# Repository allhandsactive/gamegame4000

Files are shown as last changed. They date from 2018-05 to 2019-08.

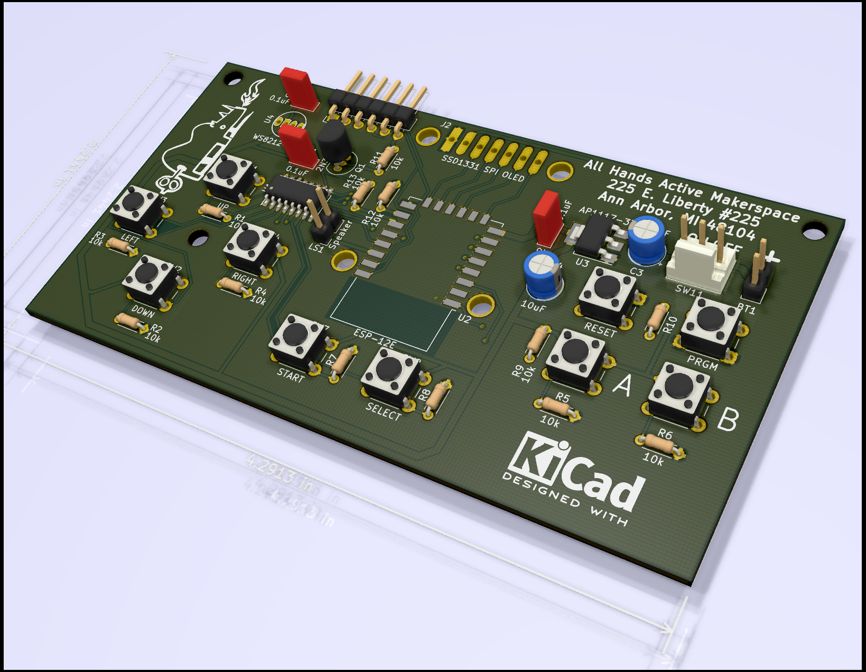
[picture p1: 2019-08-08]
pcb/Gamegame.png

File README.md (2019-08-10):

# gameGame 4000
This is the *gameGame 4000*: an ESP8266-based, wifi-enabled "badge" learn-to-solder project designed for anyone who is interested in soldering on a somewhat intermediate level, or how to program these ubiquitous microcontrollers. Along with the ESP8266, it is equipped with an SSD1331 RGB OLED display, video game controller-alike buttons, and a small speaker for bleeps and bloops.  This kit is designed by *All Hands Active* (http://www.allhandsactive.org), a 501(c)(3) not-for-profit hackerspace (http://hackerspaces.org) located in Downtown Ann Arbor, MI, USA.  The included Arkanoid demo code here is based, almost verbatim, on code from the *ssd1331* library by Alexey Dynda (@lexus2k).  We added some tweaks to accommodate our unique button handling library, and adjusted pins to match our OLED screen setup.

As any good hackerspace should, we encourage people to fully tinker with the code and designs, and to find novel uses for this project.  We'd love to hear of your projects using our badge -- please get in contact with us if you'd like to share your project!

Since it is based on the same processor, much of this documentation is copied over from our last kit, the *mktwo* badge (https://github.com/allhandsactive/mktwo-badge/blob/master/README.md)

# Build instructions on Imgur
Heads up! There are a few errors in the assembly pictures at the imgur link here.  Please follow the instructions in the captions first and foremost: https://imgur.com/gallery/5YhMqiV

### **Kit parts list**

Make sure you have the following in your kit:

1x gameGame 4000 PCB

1x ESP8266 12E or 12F microprocessor

1x SSD1331 OLED display

1x 3-AA battery holder

1x Female battery connector lead with pigtail

1x Male battery connector header

1x Toggle switch

1x Header 7-socket

1x Right-angle header 6-pin

1x Speaker 8-ohm 20mm

1x Linear regulator 1.2A 3.3v STMicroelectronics P/N LDL1117S33R

1x Shift register 8-bit Nexperia USA Inc. P/N 74HC597D,653

2x Electrolytic capacitor 10uF 50V

2x Ceramic capacitor 0.1uF 50V

4x Nylon standoff M2 x 12mm

4x Nylon nut M2

4x Nylon screw M2 x 5mm

10x Push button

12x Resistor 10k Ohm 1/8W 5%

### **Requirements**
#### **Hardware**
The safest and more reliable way to load firmware onto your *gameGame 4000* is with a USB-serial programming cable.  You will need to use an FTDI cable, like the FTDI cable here (https://www.sparkfun.com/products/9717) , *OR* you can use a cheaper cable with the Prolific *PL2303HX* chipset (look on eBay! We were able to easily find them from US sellers for under $5).  A serial voltage level of 3.3v for programming is recommended, but we've safely done it with 5v, too.  **NOTE:** Windows/Apple users, you will likely have to download a driver to use the *PL2303HX*.  Sorry, we can't provide support on how to do that.

Such cables hook up to the FTDI pin block near the bottom of the *gameGame 4000*.  Take care when hooking up the cable, because the FTDI pins on the badge are not keyed.  When you plug it into the badge, make sure the black wire on the FTDI cable faces toward the left side of the badge (assuming you are viewing the front of the badge).  In case your cable doesn't have a single plug, but a bunch of individual wires (like the Prolific ones), the pinout should be as follows, assuming the board is facing up toward you, left-to-right (*NC = No Connection*):

**BLACK NC NC GREEN WHITE NC**

The red wire from the programming cable should not be connected, which also means you will need to power the badge with the battery when programming it.

#### **Software**
We recommend a current version of the Arduino IDE (https://www.arduino.cc/en/Main/Software), either binary or git clone.

Under Arduino's preferences, *Additional Boards Manager URLs*, you will need to add:

`http://arduino.esp8266.com/stable/package_esp8266com_index.json`

Under *Tools|Board:|Boards Manager...* search for and install `esp8266`.
**NOTE: you will need to add the URL above in preferences first.**
You will also need some libraries to run the OLED screen.  Under *Sketch|Include Library|Manage Libraries...* search for `SSD1331`.  Any of those should work to varying degrees.  Try them out and experiment! If you want to try the included `arkanoid8-pcon` demo, grab the `ssd1306` library, which comes with some cool demo stuff for our `SSD1331` OLED screen.  Keep in mind that you will have to update the pin settings on the other demos since they are connected differently for this board.

Now restart the Arduino IDE.

### **Badge Programming**
#### **Wired Programming**
##### **SETUP**

Under the Arduino IDE settings (most of these seem to be defaults):

Board: "NodeMCU 1.0 (ESP-12E Module)"

CPU Frequency: "80 MHz"

Debug Port: "Disabled"

Debug Level: "None"

lwIP Variant: "v2 Lower Memory"

Flash Size: "4M (3M SPIFFS)"

Upload Speed: "460800" (try lowering this if you have issues while programming the board)

Port: (whatever port the programming cable is on.  In Linux, it'll be something like `/dev/ttyUSB0`)

Programmer: "AVRISP mkII"

Erase Flash: "Only Sketch"

##### **PROCEDURE**

Let's take a look at the `ssd1306` library's demo games.  After installing that library, you can load up the `arkanoid8-gamegame` code from this repo.

To upload your code, you need to put the badge into "write" or "programming" mode.  To do this, locate the `PRGM` and `RESET` buttons on the badge.  Hold the `PRGM` button. Press and release the `RESET` button. You may now release `PRGM`. **You will need to repeat this procedure before each firmware upload.**
You may now compile and upload as you would with any Arduino, using the Arduino IDE.

**NOTE: Some FTDI cables might not cause the ESP to reset after successful programming.  If you are observing this behavior, just use the** `RESET` **button on the badge.**

### Other notes
The speaker is linked to pin 5, if you wish to make bleeps and bloops with the `tone` function.

Other pin settings that might be useful:

For the OLED display:

sclk = 14

mosi = 13

cs = 2

rst = 0

dc = 16

For buttons (check out the example code in this repo):

pl/sload = 4

shcp/sck = 0

stcp/clk = 15

shift reg. serial output ("BUTTONS" on schematic) = 10

The board works great with three NiMH AA batteries.

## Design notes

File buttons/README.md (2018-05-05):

# gameGame_Buttons

This is a simple button tester for the upcoming gameGame soldering kit for PenguiCon 2018.

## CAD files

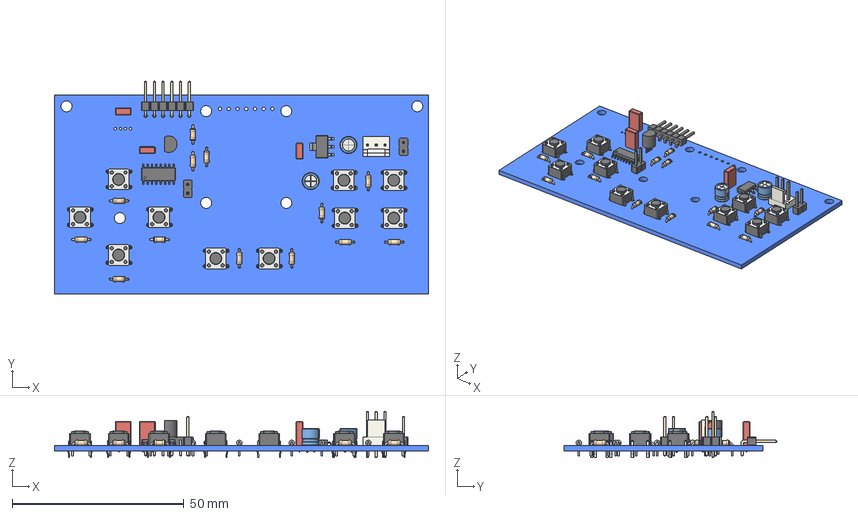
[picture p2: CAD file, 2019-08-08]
pcb/Gamegame.step
108.8 x 61.8 x 13.5 mm
Pcb
C_Rect_L46mm_W20mm_P250mm_MKS02_FKP02_
C_Rect_L46mm_W20mm_P250mm_MKS02_FKP02_001
CP_Radial_D50mm_P200mm_
CP_Radial_D50mm_P200mm_001
C_Rect_L46mm_W20mm_P250mm_MKS02_FKP02_002
PinHeader_1x06_P254mm_Horizontal_
PinHeader_1x02_P254mm_Vertical_
TO-92_Inline_Narrow_
R_Axial_DIN0204_L36mm_D16mm_P508mm_Horizontal_
R_Axial_DIN0204_L36mm_D16mm_P508mm_Horizontal_001
R_Axial_DIN0204_L36mm_D16mm_P508mm_Horizontal_002
R_Axial_DIN0204_L36mm_D16mm_P508mm_Horizontal_003
R_Axial_DIN0204_L36mm_D16mm_P508mm_Horizontal_004
R_Axial_DIN0204_L36mm_D16mm_P508mm_Horizontal_005
R_Axial_DIN0204_L36mm_D16mm_P508mm_Horizontal_006
R_Axial_DIN0204_L36mm_D16mm_P508mm_Horizontal_007
R_Axial_DIN0204_L36mm_D16mm_P508mm_Horizontal_008
R_Axial_DIN0204_L36mm_D16mm_P508mm_Horizontal_009
R_Axial_DIN0204_L36mm_D16mm_P508mm_Horizontal_010
R_Axial_DIN0204_L36mm_D16mm_P508mm_Horizontal_011
R_Axial_DIN0204_L36mm_D16mm_P508mm_Horizontal_012
SW_PUSH_6mm_
SW_PUSH_6mm_001
SW_PUSH_6mm_002
SW_PUSH_6mm_003
SW_PUSH_6mm_004
SW_PUSH_6mm_005
SW_PUSH_6mm_006
SW_PUSH_6mm_007
SW_PUSH_6mm_008
SW_PUSH_6mm_009
Fan_Pin_Header_Straight_1x03_
SOIC_16_39x99mm_P127mm_
SOT_223_
PinHeader_1x02_P254mm_Vertical_001

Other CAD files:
pcb/Gamegame.FCStd

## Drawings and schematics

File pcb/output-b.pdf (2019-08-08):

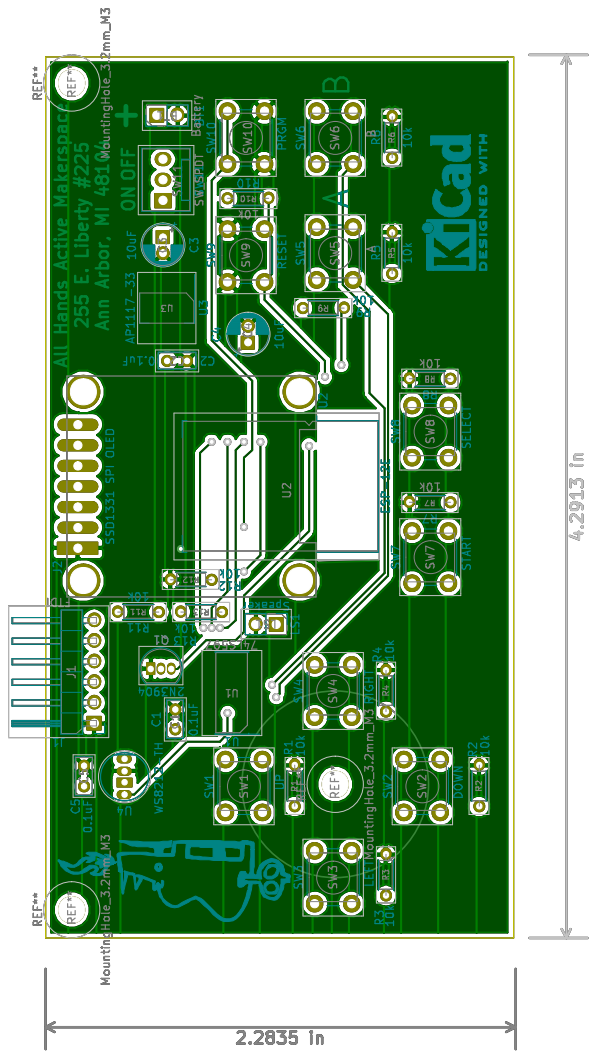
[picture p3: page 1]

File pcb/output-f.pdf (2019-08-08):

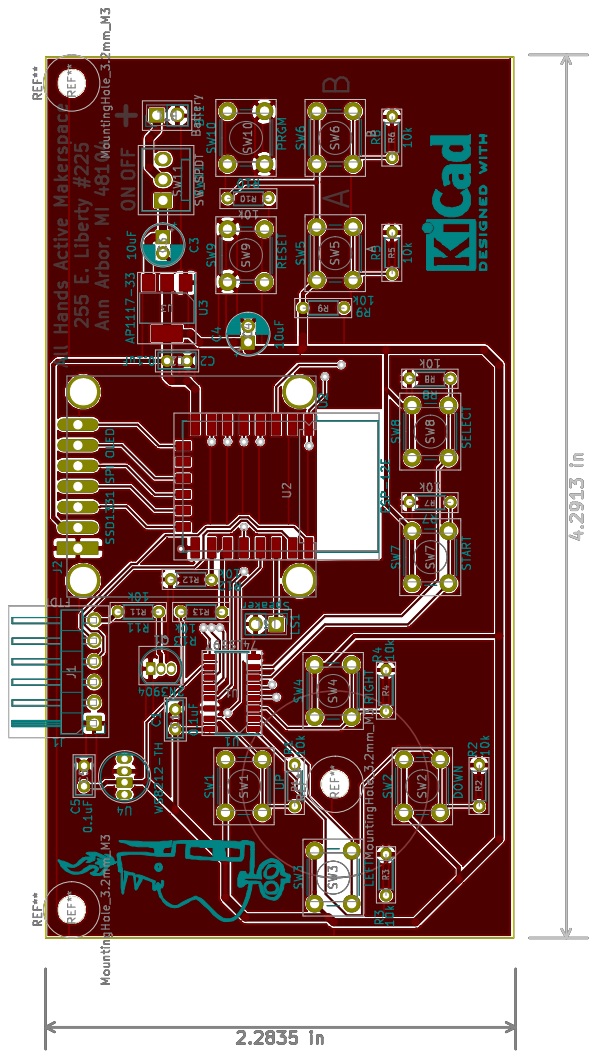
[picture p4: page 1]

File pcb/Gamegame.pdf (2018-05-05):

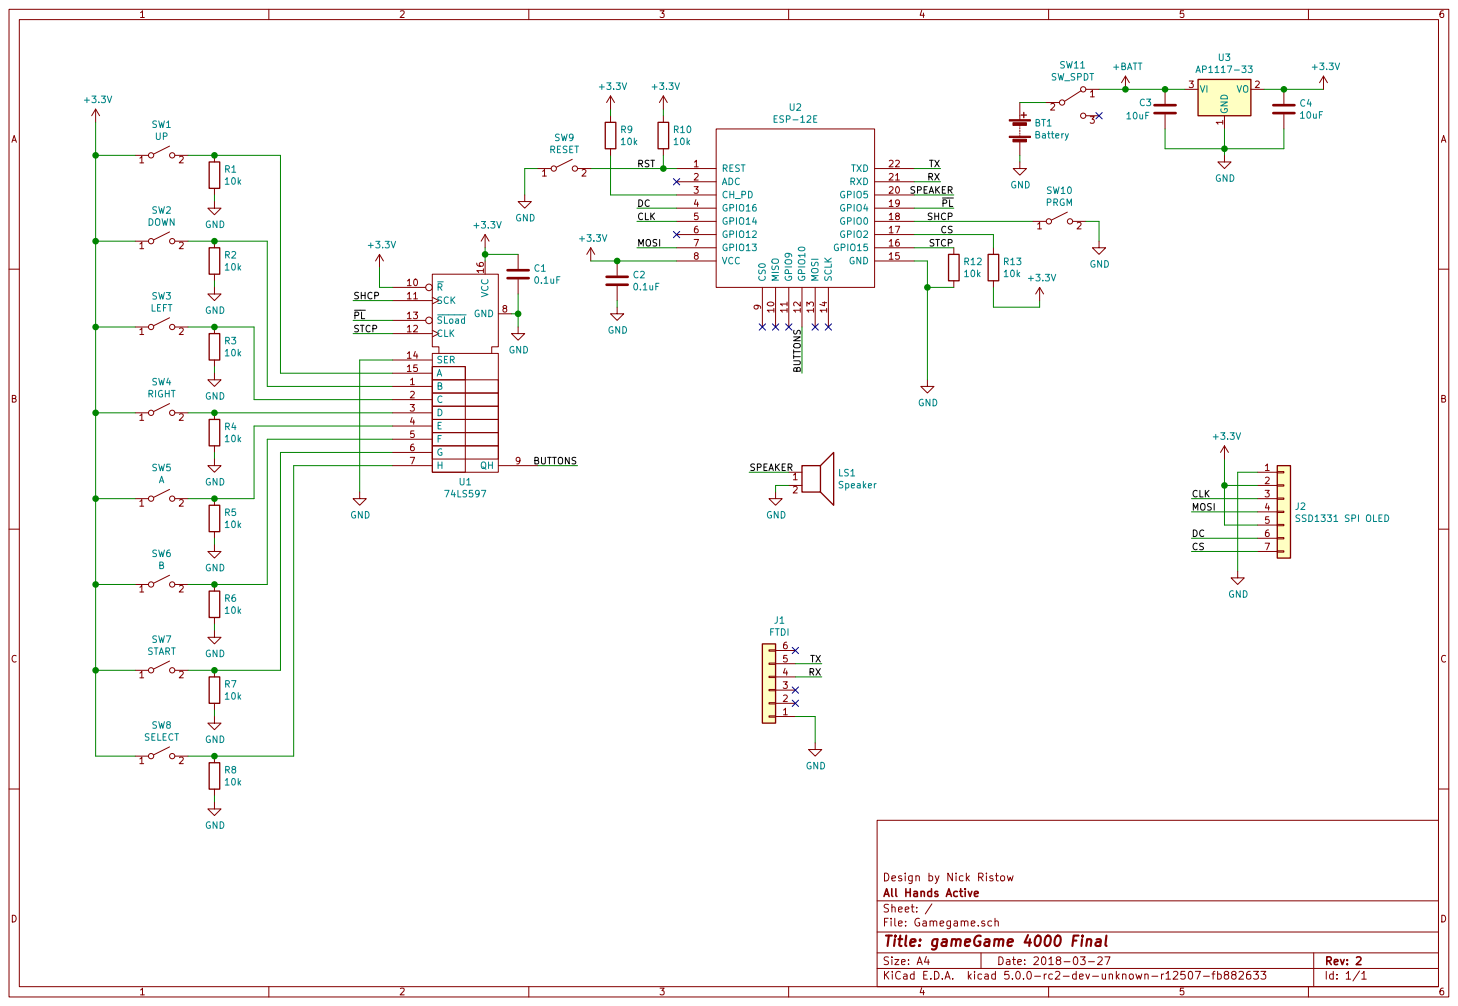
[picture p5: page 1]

File: Gamegame.sch Sheet: / All Hands Active Design by Nick Ristow

Id: 1/1 Title: gameGame 4000 Final

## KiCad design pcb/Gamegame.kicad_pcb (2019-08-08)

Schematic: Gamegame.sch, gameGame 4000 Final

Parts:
BT1: Battery; PinHeader_1x02_P2.54mm_Vertical
C1, C2: 0.1uF; C_Rect_L4.6mm_W2.0mm_P2.50mm_MKS02_FKP02
C3, C4: 10uF; C_Rect_L4.6mm_W2.0mm_P2.50mm_MKS02_FKP02
J1: FTDI; PinHeader_1x06_P2.54mm_Horizontal
J2: SSD1331 SPI OLED; SD1131
LS1: Speaker; PinHeader_1x02_P2.54mm_Vertical
R1, R2, R3, R4, R5, R6, R7, R8, R9, R10, R12, R13: 10k; R_Axial_DIN0204_L3.6mm_D1.6mm_P5.08mm_Horizontal
SW1: UP; SW_PUSH_6mm
SW2: DOWN; SW_PUSH_6mm
SW3: LEFT; SW_PUSH_6mm
SW4: RIGHT; SW_PUSH_6mm
SW5: A; SW_PUSH_6mm
SW6: B; SW_PUSH_6mm
SW7: START; SW_PUSH_6mm
SW8: SELECT; SW_PUSH_6mm
SW9: RESET; SW_PUSH_6mm
SW10: PRGM; SW_PUSH_6mm
SW11: SW_SPDT; FanPinHeader_1x03_P2.54mm_Vertical
U1: 74LS597; SOIC-16_3.9x9.9mm_P1.27mm
U2: ESP-12E
U3: AP1117-33; SOT-223-3_TabPin2

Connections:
+3V3: C1.1, C2.1, C4.1, J2.2, J2.5, R9.1, R10.1, R13.2, SW1.1, SW2.1, SW3.1, SW4.1, SW5.1, SW6.1, SW7.1, SW8.1, U1.10, U1.16, U2.8 (VCC), U3.2 (VO)
+BATT: C3.1, SW11.1, U3.3 (VI)
/BUTTONS: U1.9, U2.12 (GPIO10)
/CLK: J2.3, U2.5 (GPIO14)
/CS: J2.7, R13.1, U2.17 (GPIO2)
/DC: J2.6, U2.4 (GPIO16)
/MOSI: J2.4, U2.7 (GPIO13)
/RST: R10.2, SW9.2, U2.1 (REST)
/RX: J1.4, U2.21 (RXD)
/SHCP: SW10.1, U1.11, U2.18 (GPIO0)
/SPEAKER: LS1.1, U2.20 (GPIO5)
/STCP: R12.1, U1.12, U2.16 (GPIO15)
/TX: J1.5, U2.22 (TXD)
/~PL: U1.13, U2.19 (GPIO4)
GND: BT1.2, C1.2, C2.2, C3.2, C4.2, J1.1, J2.1, LS1.2, R1.2, R2.2, R3.2, R4.2, R5.2, R6.2, R7.2, R8.2, R12.2, SW9.1, SW10.2, U1.8, U1.14, U2.15 (GND), U3.1 (GND)
unnamed: BT1.1, SW11.2
unnamed: R1.1, SW1.2, U1.15
unnamed: R2.1, SW2.2, U1.1
unnamed: R3.1, SW3.2, U1.2
unnamed: R4.1, SW4.2, U1.3
unnamed: R5.1, SW5.2, U1.4
unnamed: R6.1, SW6.2, U1.5
unnamed: R7.1, SW7.2, U1.6
unnamed: R8.1, SW8.2, U1.7
unnamed: R9.2, U2.3 (CH_PD)

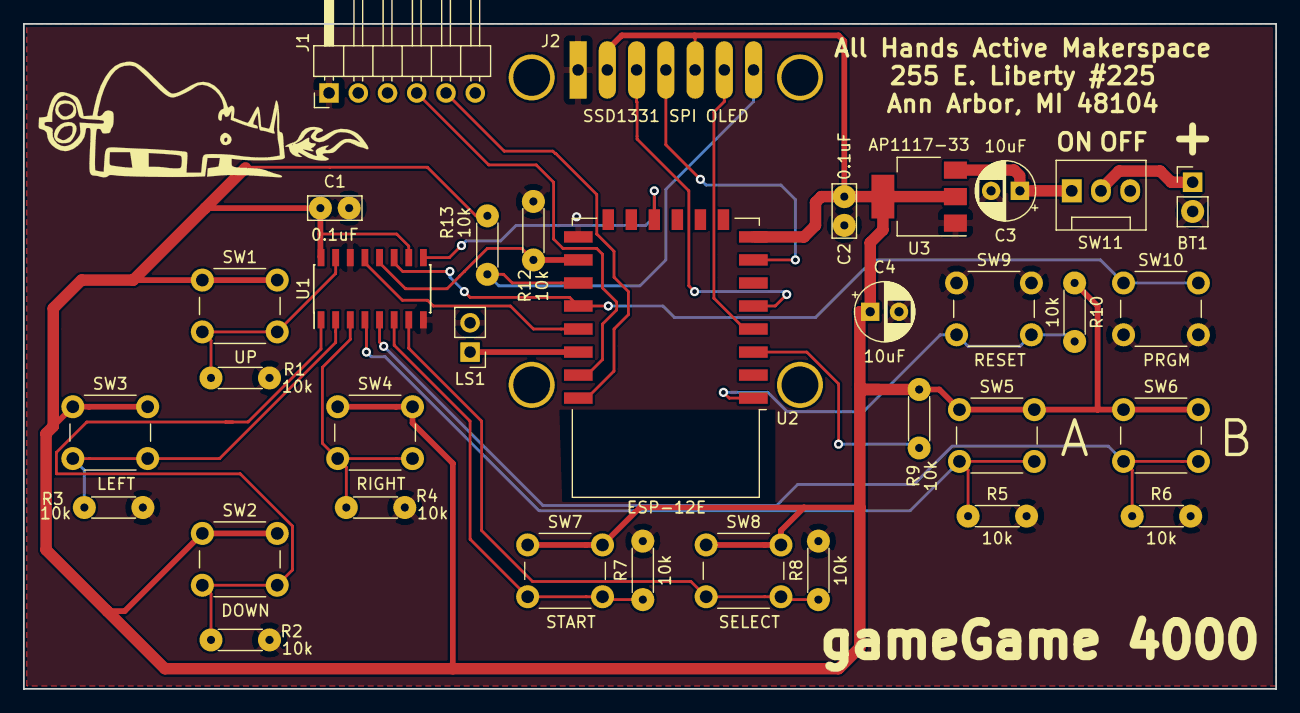
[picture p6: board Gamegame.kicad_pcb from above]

Board: 2 copper layers, 108.8 x 57.8 mm, 34 parts (0 on the bottom side), 25 nets.

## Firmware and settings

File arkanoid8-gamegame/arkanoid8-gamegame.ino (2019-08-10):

/*
    MIT License

    Copyright (c) 2018, Alexey Dynda

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
    THE SOFTWARE IS PROVIDED "AS IS", WITHOUT WARRANTY OF ANY KIND, EXPRESS OR
    IMPLIED, INCLUDING BUT NOT LIMITED TO THE WARRANTIES OF MERCHANTABILITY,
    FITNESS FOR A PARTICULAR PURPOSE AND NONINFRINGEMENT. IN NO EVENT SHALL THE
    AUTHORS OR COPYRIGHT HOLDERS BE LIABLE FOR ANY CLAIM, DAMAGES OR OTHER
    LIABILITY, WHETHER IN AN ACTION OF CONTRACT, TORT OR OTHERWISE, ARISING FROM,
    OUT OF OR IN CONNECTION WITH THE SOFTWARE OR THE USE OR OTHER DEALINGS IN THE
    SOFTWARE.
*/
/**
 *   Nano/Atmega328 PINS: connect LCD to D5 (D/C), D4 (CS), D3 (RES), D11(DIN), D13(CLK)
 *   Attiny SPI PINS:     connect LCD to D4 (D/C), GND (CS), D3 (RES), D1(DIN), D2(CLK)
 *   ESP8266: connect LCD to D1(D/C), D2(CS), RX(RES), D7(DIN), D5(CLK)
 */

#include "ssd1306.h"
#include "nano_engine.h"

#include "arkanoid.h"
#include "levels.h"

#define PIX_BITS  2

#include <buttons.h>

//Set up the buttons for the gameGame 4000.  See the `button` code for more info.
Buttons button(4,0,15,10);

#define SPEAKER 5

NanoEngine8 engine;

static uint8_t g_level = 0;
static uint8_t g_score = 0;
static const NanoRect gameArea = { {16, 0}, {79, 63} };
static const NanoRect blockArea = { {0, 8},
                                    {BLOCKS_PER_ROW*8 - 1, 8 + BLOCK_NUM_ROWS*4 - 1} };

union
{
    struct
    {
        lcdint_t intro_y;
        lcdint_t pauseFrames;
    } intro;
    struct
    {
        lcdint_t intro_y;
        lcdint_t pauseFrames;
    } info;
    struct
    {
        NanoRect  platform;  // platform position on the screen
        NanoPoint ball;      // ball position on the screen
        NanoPoint ballScaled;// ball position in ^PIX_BITS coordinates
        NanoPoint ballSpeed; // ball speed in *2 coordinates
        uint8_t   blocks[BLOCK_NUM_ROWS][MAX_BLOCKS_PER_ROW];
        uint8_t   blocksLeft;
        uint8_t   frames;
    } battleField;
} gameState;

void startBattleField(bool reload);

bool drawIntro(void)
{
    engine.canvas.clear();
    engine.canvas.setColor(RGB_COLOR8(255,0,0));
    engine.canvas.drawBitmap1(0, gameState.intro.intro_y, 96, 24, arkanoid_2);
    return true;
}

void introLoop(void)
{
    if (gameState.intro.intro_y < 16)
    {
        engine.refresh( 0, gameState.intro.intro_y, 95, gameState.intro.intro_y + 24 );
        gameState.intro.intro_y++;
    }
    else
    {
        gameState.intro.pauseFrames++;
        if (gameState.intro.pauseFrames > engine.getFrameRate() * 3 )
        {
            startBattleField( true );
        }
    }
}

void startIntro(void)
{
    engine.refresh();
    g_level = 0;
    g_score = 0;
    gameState.intro.intro_y = -24;
    gameState.intro.pauseFrames = 0;
    engine.drawCallback( drawIntro );
    engine.loopCallback( introLoop );
}

bool drawBattleField(void)
{
    /* If engine requests to redraw main game field */
    if (gameArea.contains(engine.canvas.rect()))
    {
        /* Set non-transparent mode */
        engine.canvas.setMode(CANVAS_MODE_BASIC);
        engine.canvas.setColor(RGB_COLOR8(0,0,64));
        NanoRect tileBlocks = engine.canvas.rect() >> 3;
        tileBlocks.crop(gameArea >> 3);
        for (uint8_t row = tileBlocks.p1.y; row <= tileBlocks.p2.y; row++)
            for (uint8_t col = tileBlocks.p1.x; col <= tileBlocks.p2.x; col++)
                engine.canvas.drawBitmap1(col << 3, row << 3, 8, 8, bgTile);
        engine.canvas.setColor(RGB_COLOR8(255,255,255));
        engine.canvas.drawHLine(gameArea.p1.x,gameArea.p1.y,gameArea.p2.x);

        /* Now draw everything in game coordinates */
        engine.worldCoordinates();
        engine.canvas.setColor(RGB_COLOR8(0,128,255));
        engine.canvas.drawRect(gameState.battleField.platform);
        engine.canvas.setColor(RGB_COLOR8(0,0,0));
        engine.canvas.putPixel(gameState.battleField.platform.p1);
        engine.canvas.putPixel(gameState.battleField.platform.p2.x,
                               gameState.battleField.platform.p1.y);
        for (uint8_t r = 0; r<BLOCK_NUM_ROWS; r++)
        {
            for (uint8_t bl = 0; bl<BLOCKS_PER_ROW; bl++)
            {
                uint8_t block = gameState.battleField.blocks[r][bl];
                if (block)
                {
                     NanoRect rect = {{bl*8, r*4}, {bl*8 + 8, r*4+4}};
                     rect += blockArea.p1;
                     engine.canvas.setColor(blockColors[block]);
                     engine.canvas.fillRect(rect);
                     engine.canvas.setColor(0);
                     engine.canvas.drawRect(rect);
                }
            }
         }
         engine.canvas.setColor(RGB_COLOR8(255,255,255));
         engine.canvas.putPixel(gameState.battleField.ball);
    }
    else
    {
        char str[8] = {0};
        engine.canvas.clear();
        engine.canvas.setColor(RGB_COLOR8(255,255,255));
        engine.canvas.drawVLine(gameArea.p1.x-1,0,64);
        engine.canvas.drawVLine(gameArea.p2.x+1,0,64);
        utoa(g_score, str, 10);
        engine.canvas.setColor(RGB_COLOR8(192,192,192));
        engine.canvas.printFixed(gameArea.p2.x+3, 16, str );
    }
    return true;
}

/* Moves platform right or left according to pressed keys */
void movePlatform(void)
{
    //Here is another change to make the inputs work on the gameGame 4000.
    uint8_t but = button.readButtons();
    

    if ((but & Buttons::LEFT) && (gameState.battleField.platform.p1.x > 0))
    {
        engine.refreshWorld( gameState.battleField.platform );
        gameState.battleField.platform.move(-1, 0);
        engine.refreshWorld( gameState.battleField.platform );
    }
    if ((but & Buttons::RIGHT) && (gameState.battleField.platform.p2.x < gameArea.width() - 1))
    {
        engine.refreshWorld( gameState.battleField.platform );
        gameState.battleField.platform.move(+1, 0);
        engine.refreshWorld( gameState.battleField.platform );
    }
}

bool checkBlockHit(void)
{
    if (!blockArea.collision(gameState.battleField.ball))
    {
        return false;
    }
    NanoPoint p = gameState.battleField.ball - blockArea.p1;
    uint8_t row = p.y >> 2;
    uint8_t column = p.x >> 3;
    if (!gameState.battleField.blocks[row][column])
    {
        return false;
    }
    gameState.battleField.blocks[row][column] = 0;
    gameState.battleField.blocksLeft--;
    g_score++;
    engine.refreshWorld( gameArea.p2.x + 1, 0, 95, 63 );
    if (((p.y & 3) == 2) || (p.y & 3) == 1)
    {
        gameState.battleField.ballSpeed.x = -gameState.battleField.ballSpeed.x;
    }
    else
    {
        gameState.battleField.ballSpeed.y = -gameState.battleField.ballSpeed.y;
    }
    engine.refreshWorld( gameState.battleField.ball );
    return true;
}

bool checkPlatformHit()
{
    if (gameState.battleField.platform.collisionX( gameState.battleField.ball.x ) &&
        !gameState.battleField.platform.above( gameState.battleField.ball ) &&
        !gameState.battleField.platform.below( gameState.battleField.ball ) )
    {
        if (gameState.battleField.ball.x < gameState.battleField.platform.p1.x + 3)
        {
            gameState.battleField.ballSpeed.x = -3;
            gameState.battleField.ballSpeed.y = -gameState.battleField.ballSpeed.y;
        }
        else if (gameState.battleField.ball.x > gameState.battleField.platform.p2.x - 3)
        {
            gameState.battleField.ballSpeed.x = +3;
            gameState.battleField.ballSpeed.y = -gameState.battleField.ballSpeed.y;
        }
        else
        {
            gameState.battleField.ballSpeed.x = gameState.battleField.ballSpeed.x > 0 ? 2: -2;
            gameState.battleField.ballSpeed.y = -gameState.battleField.ballSpeed.y;
        }
        return true;
    }
    return false;
}

bool checkGameAreaHit(void)
{
    bool hit = false;
    if ((gameState.battleField.ball.x < 0) ||
        (gameState.battleField.ball.x >= gameArea.width()))
    {
        hit = true;
        gameState.battleField.ballSpeed.x = -gameState.battleField.ballSpeed.x;
    }
    if ((gameState.battleField.ball.y < 0) ||
        (gameState.battleField.ball.y >= gameArea.height()))
    {
        hit = true;
        gameState.battleField.ballSpeed.y = -gameState.battleField.ballSpeed.y;
        if (gameState.battleField.ball.y >= gameArea.height())
        {
             startBattleField( false );
        }
    }
    return hit;
}

void moveBall(void)
{
    engine.refreshWorld( gameState.battleField.ball );
    bool moveBall;
    do
    {
        gameState.battleField.ballScaled += gameState.battleField.ballSpeed;
        gameState.battleField.ball = gameState.battleField.ballScaled >> PIX_BITS;
        moveBall = false;
        if (checkGameAreaHit())
        {
            moveBall = true;
            tone(SPEAKER, 880, 50);
        }
        if (checkPlatformHit())
        {
            moveBall = true;
            tone(SPEAKER, 440, 50);
        }
        if (checkBlockHit())
        {
            moveBall = true;
            tone(SPEAKER, 220, 50);
        }
    }
    while (moveBall);
    engine.refreshWorld( gameState.battleField.ball );
}

void battleFieldLoop(void)
{
    movePlatform();
    moveBall();
    /* Refresh debug information if we need it */
    gameState.battleField.frames++;
    if (gameState.battleField.blocksLeft == 0)
    {
        g_level++;
        startBattleField( true );
    }
}

void loadLevel(void)
{
    /* Loading level */
    if (g_level > MAX_LEVELS)
    {
       g_level = MAX_LEVELS;
    }
    gameState.battleField.blocksLeft = 0;
    for (uint8_t i =0; i<BLOCKS_PER_ROW; i++)
    {
        for (uint8_t j=0; j<BLOCK_NUM_ROWS; j++)
        {
            uint8_t block = pgm_read_byte( &levels[g_level][j][i] );
            gameState.battleField.blocks[j][i] = block;
            if (block)
            {
                gameState.battleField.blocksLeft++;
            }
        }
    }
    gameState.battleField.frames = 0;
}

void startBattleField(bool reload)
{
    engine.refresh();
    gameState.battleField.platform.setRect( 4, 56, 15, 58 );
    gameState.battleField.ball.setPoint( 9, 55);
    gameState.battleField.ballScaled = gameState.battleField.ball << PIX_BITS;
    gameState.battleField.ballSpeed.setPoint( 3, -(1<<PIX_BITS) );
    engine.drawCallback( drawBattleField );
    engine.loopCallback( battleFieldLoop );
    if ( reload )
    {
        loadLevel();
    }

    /* Show level info in popup message */
    char levelInfo[8] = "LEVEL X";
    levelInfo[6] = g_level + '0';
    engine.notify(levelInfo);
}

void setup()
{
    /* Set font to use in the game. The font has only capital letters and digits */
    ssd1306_setFixedFont(ssd1306xled_font6x8_AB);

    /* Init SPI oled display. 3 - RESET, 4 - CS (can be omitted, oled CS must be pulled down), 5 - D/C */

    /* ssd1351 must be initialized in Horizontal addressing mode */
//    ssd1351_128x128_spi_init(3, 4, 5);

    /* il9163 must be initialized in Horizontal addressing mode */
//    il9163_128x128_spi_init(3, 4, 5);

    /* ssd1331 must be initialized in Horizontal addressing mode */
    // For gameGame 4000, RESET should be 0, CS is pin 2, and DC is pin 16.
    ssd1331_96x64_spi_init(0, 2, 16);

    /* Configure engine to use ZKeypand on A0 as control board. */
    //engine.connectZKeypad(0);

    /* Start engine */
    engine.begin();

    /* Set frame rate. 30 fps is too slow */
    engine.setFrameRate(45);

    engine.moveTo({ -gameArea.p1.x, -gameArea.p1.y });

    startIntro();
}

void loop()
{
    if (!engine.nextFrame()) return;
    engine.display();
}

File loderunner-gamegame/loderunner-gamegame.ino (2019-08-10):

/*
    MIT License

    Copyright (c) 2018, Alexey Dynda

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
    THE SOFTWARE IS PROVIDED "AS IS", WITHOUT WARRANTY OF ANY KIND, EXPRESS OR
    IMPLIED, INCLUDING BUT NOT LIMITED TO THE WARRANTIES OF MERCHANTABILITY,
    FITNESS FOR A PARTICULAR PURPOSE AND NONINFRINGEMENT. IN NO EVENT SHALL THE
    AUTHORS OR COPYRIGHT HOLDERS BE LIABLE FOR ANY CLAIM, DAMAGES OR OTHER
    LIABILITY, WHETHER IN AN ACTION OF CONTRACT, TORT OR OTHERWISE, ARISING FROM,
    OUT OF OR IN CONNECTION WITH THE SOFTWARE OR THE USE OR OTHER DEALINGS IN THE
    SOFTWARE.
*/
/*
 *   Attiny85 PINS
 *             ____
 *   RESET   -|_|  |- 3V
 *   SCL (3) -|    |- (2)
 *   SDA (4) -|    |- (1) - BUZZER
 *   GND     -|____|- (0) - BUTTONS module
 *
 *   Atmega328 PINS with i2c SSD1306 to A4/A5, BUZZER on D8,
 *   Z-keypad ADC module on A0 pin.
 *   If you want to use GPIO keys, uncomment USE_GPIO_BUTTONS below
 *
 *   Atmega328 PINS with spi Nokia 5110 LCD:
 *   LCD RST to D3
 *   LCD CES to D4
 *   LCD DC to  D5
 *   LCD DIN to D11
 *   LCD CLK to D13
 *   LCD BL to  VCC
 */

#include "game_basic.h"
#include "ninja.h"
#include "sprites.h"
#include "intf/ssd1306_interface.h"
#include "intf/spi/ssd1306_spi.h"

#include <buttons.h>

// Uncomment if you have ssd1331 oled display
//#define SSD1331_ACCELERATION

// Uncomment if you want to use gpio buttons
//#define USE_GPIO_BUTTONS

#if defined(__AVR_ATtiny25__) | defined(__AVR_ATtiny45__) | defined(__AVR_ATtiny85__)
#define BUZZER      5
#define BUTTON_PIN  0
#else // For Arduino Nano/Atmega328 we use different pins
#define BUZZER      5
#define BUTTON_PIN  0
#ifdef USE_GPIO_BUTTONS
static const uint8_t g_buttonsPins[6] = { 2, 6, 7, 8, 9, 12 };
#endif

#endif

//Set up gameGame buttons
Buttons button(4,0,15,10);

const NanoRect game_window = { {0, 0}, {95, 63} };

uint8_t blockColors[] =
{
    RGB_COLOR8(255,96,0),
    RGB_COLOR8(255,255,192),
    RGB_COLOR8(255,255,255),
    RGB_COLOR8(255,255,64),
    RGB_COLOR8(128,128,128),
};

/**
 * Just produces some sound depending on params
 */
void beep(int bCount,int bDelay);

NanoFixedSprite<GraphicsEngine, engine> player( { 8, 8 }, { 8, 8 }, playerFlyingImage[0][0] );

/* The variable is used for player animation      *
 * The graphics defined for the hero has 2 images *
 * for each direction. So, the variable is either *
 * 0 or 1. */
uint8_t  playerAnimation = 0;

/* Timestamp when playerAnimation was changed last time */
uint16_t playerAnimationTs = 0;

/* Number of coins collected */
uint8_t  goldCollection = 0;

void showGameInfo()
{
    engine.canvas.setMode(CANVAS_MODE_TRANSPARENT);
    engine.canvas.setColor(RGB_COLOR8(0,0,0));
    engine.canvas.drawBitmap1(1, 1, 8, 8, coinImage);
    engine.canvas.setColor(RGB_COLOR8(255,255,0));
    engine.canvas.drawBitmap1(0, 0, 8, 8, coinImage);

    ssd1306_setFixedFont(digital_font5x7_AB);
    char score[3] = {goldCollection/10 + '0', goldCollection%10 + '0', 0};
    engine.canvas.setColor(RGB_COLOR8(0,0,0));
    engine.canvas.printFixed(9,1,score);
    engine.canvas.setColor(RGB_COLOR8(255,255,255));
    engine.canvas.printFixed(8,0,score);
    ssd1306_setFixedFont(digital_font5x7_AB);
}

static bool onDraw()
{
    engine.canvas.clear();
    engine.canvas.setMode(CANVAS_MODE_BASIC);
    if (game_window.containsPartOf( engine.canvas.rect() ))
    {
        engine.worldCoordinates();
        NanoRect blocks = rect_to_blocks( engine.canvas.rect() );
        for (uint8_t row = max(0,blocks.p1.y);
                     row <= min(13,blocks.p2.y); row++)
        {
            for (uint8_t col = max(0,blocks.p1.x);
                         col <= min(23,blocks.p2.x); col++)
            {
                uint8_t blockType = block_value({col,row});
                if (blockType != 0)
                {
                    engine.canvas.setColor(blockColors[blockType - 1]);
                    NanoPoint pos = block_to_pos({col,row});
                    engine.canvas.drawBitmap1(pos.x, pos.y,
                                          8, 8, bgSprites[blockType - 1]);
                }
            }
        }
        engine.canvas.setMode(CANVAS_MODE_TRANSPARENT);
        engine.canvas.setColor(RGB_COLOR8(64,255,255));
        player.draw();
        engine.canvas.setColor(RGB_COLOR8(64,64,255));
        ninja.draw();
        engine.localCoordinates();
    }
    showGameInfo();
    return true;
}

static NanoPoint calc_new_screen_position()
{
    NanoPoint position = engine.getPosition() + game_window.p1;
    if (player.x() - position.x >= game_window.width() - 24)
    {
        position.x = min(player.x() - (game_window.width() - 24), 128);
    }
    else if (player.x() - position.x < 24)
    {
        position.x = max(0, player.x() - 24);
    }
    if (player.y() - position.y >= game_window.height() - 24)
    {
        position.y = min(player.y() - (game_window.height() - 24), 64);
    }
    else if (player.y() - position.y < 24)
    {
        position.y = max(0, player.y() - 24);
    }
    return position - game_window.p1;
}

#ifdef SSD1331_ACCELERATION
static void moveGameScreen()
{
    NanoPoint position = calc_new_screen_position();
    if (position != engine.getPosition())
    {
        NanoPoint delta = position - engine.getPosition();
        NanoRect block = game_window + delta;
        block.crop(game_window);
        // Copy most part of OLED content via hardware accelerator
        ssd1331_copyBlock(block.p1.x, block.p1.y, block.p2.x, block.p2.y,
                          block.p1.x - delta.x, block.p1.y - delta.y);
        // give some time oled to complete HW copy operation
        delayMicroseconds(250);
        engine.moveTo( position );
        // Now tell the engine to redraw only new areas
        if ( delta.x > 0)
            engine.refresh(game_window.p2.x - delta.x, game_window.p1.y, game_window.p2.x, game_window.p2.y);
        else if ( delta.x < 0 )
            engine.refresh(game_window.p1.x, game_window.p1.y, game_window.p1.x - delta.x, game_window.p2.y);
        if ( delta.y > 0)
            engine.refresh(game_window.p1.x, game_window.p2.y - delta.y, game_window.p2.x, game_window.p2.y);
        else if ( delta.y < 0 )
            engine.refresh(game_window.p1.x, game_window.p1.y, game_window.p2.x, game_window.p1.y - delta.y);
        // refresh status line
        engine.refresh(0,0,23,7);
    }
}

#else // NO SSD1331 Acceleration

static void moveGameScreen()
{
    NanoPoint position = calc_new_screen_position();
    if (position != engine.getPosition())
    {
        engine.moveTo( position );
        engine.refresh( game_window );
    }
}

#endif
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

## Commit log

2018-05-05 Added buttons example, and docs directory.
2018-05-05 Adding demo code for funteims. Added schematic.
2018-05-22 added pcb files
    [Gamegame-B.Cu.gbl, Gamegame-B.Mask.gbs, Gamegame-Edge.Cuts.gm1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]
